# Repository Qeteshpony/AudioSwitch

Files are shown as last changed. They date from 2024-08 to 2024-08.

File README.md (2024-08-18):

# AudioSwitch



3D Render

[Hardware Documentation](https://qeteshpony.github.io/AudioSwitch)

Takes one 6.3mm stereo or two 6.3mm mono plugs on each in- and output

The signal goes from the input to one of the outputs, depending on the switch position

Always use the left channel connector for stereo plugs, leave the right channel open in that case

Dual mono and single stereo conections can be mixed

### Needed parts

The audio connectors are NEUTRIK NRJ6HF - I use the -AU version because I can, but the standard version should work just fine

The switch is a C&K PVA2EEH31.7NV2

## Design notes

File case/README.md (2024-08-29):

The case is designed in a way so both parts can be printed without any supports. I printed them with a 0.6mm nozzle with .25mm layer height and arachne enabled and they came out perfect. 

Use two self-tapping M3-Screws to close the case with the board sandwiched between the two parts. 

The included lbx file can be printed on a P-Touch printer with 12mm tape. After cutting of a few mm on the right it can be aligned with the connectors. I used clear tape with white ink to get a nice effect on a black case.

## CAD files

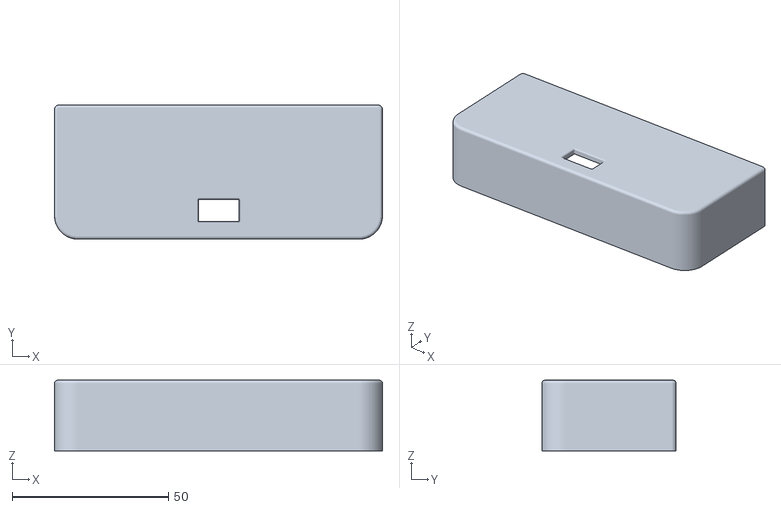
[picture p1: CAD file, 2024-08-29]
case/AudioSwitch Case Top.stl
105.0 x 43.0 x 22.6

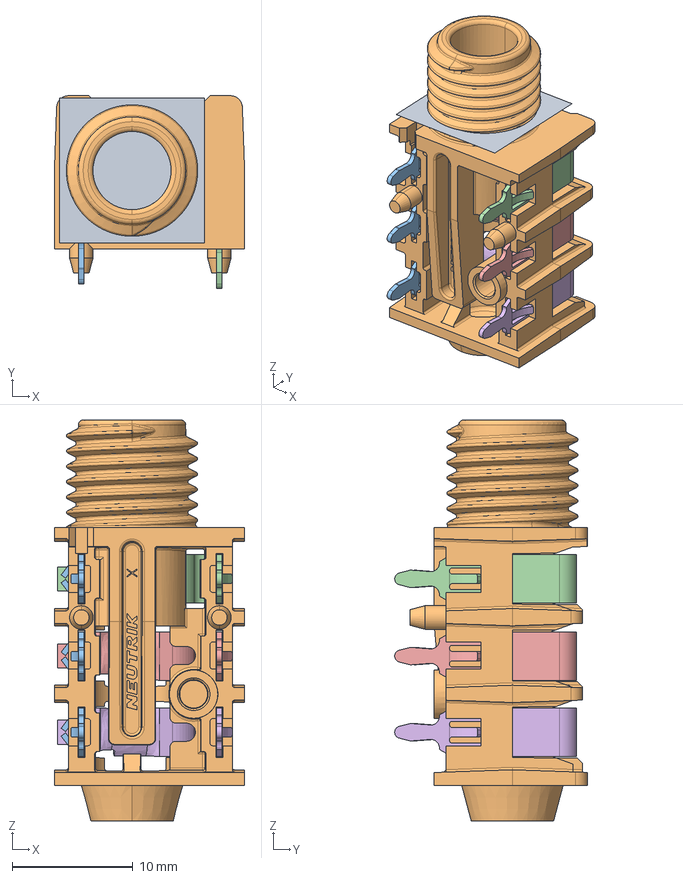
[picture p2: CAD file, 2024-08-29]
pcb/nrj6hf.stp
15.8 x 16.0 x 33.2 mm

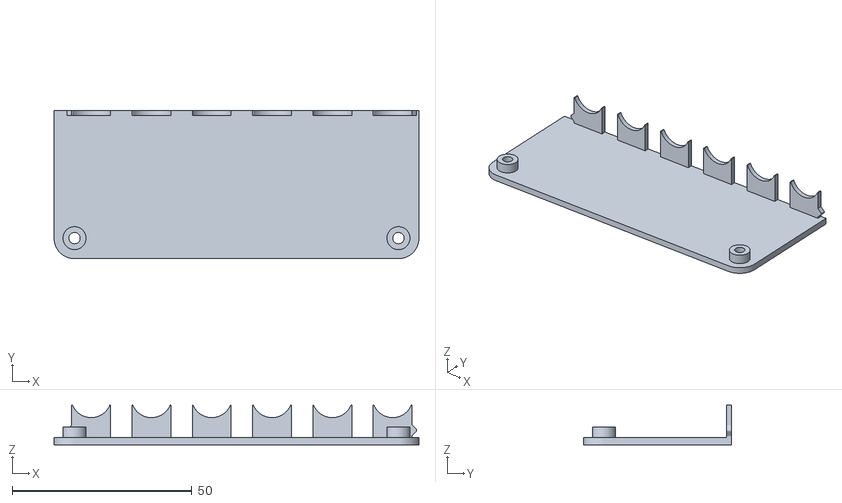
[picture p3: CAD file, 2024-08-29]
case/AudioSwitch Case Bottom.stl
101.4 x 41.2 x 11.0

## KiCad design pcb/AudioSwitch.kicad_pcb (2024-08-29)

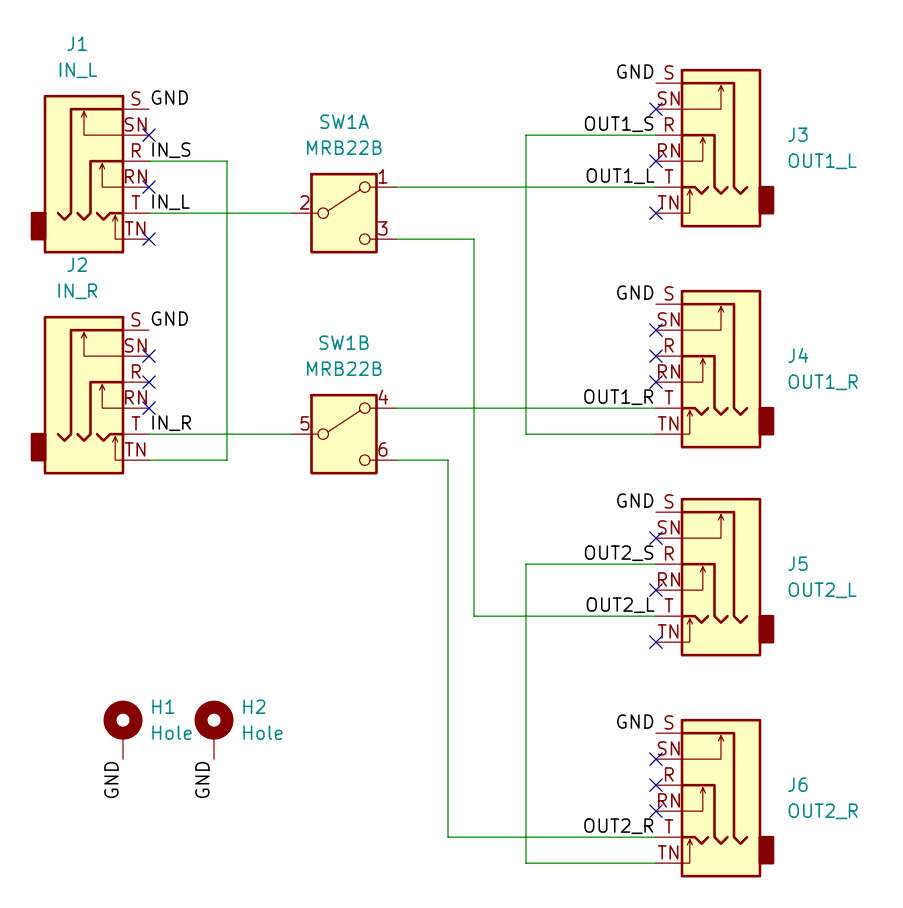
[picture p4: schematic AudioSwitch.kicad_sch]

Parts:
H1, H2: Hole; MountingHole_3.2mm_M3_Pad_Via
J1: IN_L; Jack_6.35mm_Neutrik_NRJ6HF-AU_Horizontal
J2: IN_R; Jack_6.35mm_Neutrik_NRJ6HF-AU_Horizontal
J3: OUT1_L; Jack_6.35mm_Neutrik_NRJ6HF-AU_Horizontal
J4: OUT1_R; Jack_6.35mm_Neutrik_NRJ6HF-AU_Horizontal
J5: OUT2_L; Jack_6.35mm_Neutrik_NRJ6HF-AU_Horizontal
J6: OUT2_R; Jack_6.35mm_Neutrik_NRJ6HF-AU_Horizontal
SW1: MRB22B; SW_Push_2P2T_Toggle_CK_PVA2xxH3xxxxxxV2

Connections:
/GND: H1.1, H2.1, J1.S, J2.S, J3.S, J4.S, J5.S, J6.S
/IN_L: J1.T, SW1.2 (B)
/IN_R: J2.T, SW1.5 (B)
/IN_S: J1.R, J2.TN
/OUT1_L: J3.T, SW1.1 (A)
/OUT1_R: J4.T, SW1.4 (A)
/OUT1_S: J3.R, J4.TN
/OUT2_L: J5.T, SW1.3 (C)
/OUT2_R: J6.T, SW1.6 (C)
/OUT2_S: J5.R, J6.TN

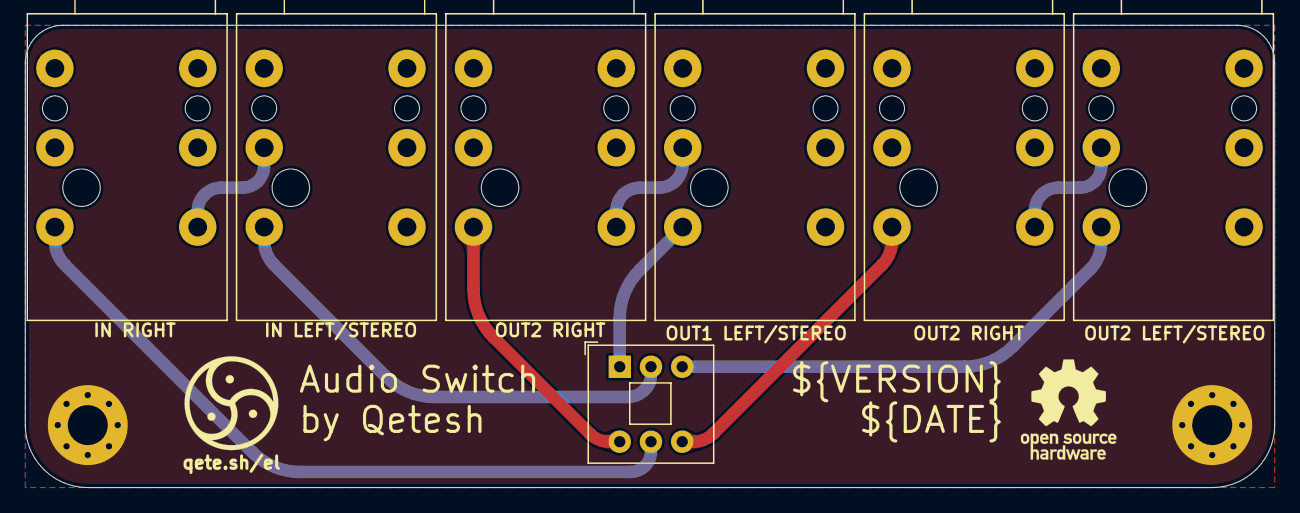
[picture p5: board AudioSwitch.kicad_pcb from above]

Board: 2 copper layers, 100.0 x 37.0 mm, 9 parts (0 on the bottom side), 10 nets.

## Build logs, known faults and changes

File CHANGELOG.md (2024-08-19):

# Changelog

## 1.0.0 (2024-08-19)

### Features

* initial commit ([d3c52cb](https://github.com/Qeteshpony/AudioSwitch/commit/d3c52cb936feac413439092e50b9f1e02347a7c6))

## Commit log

2024-08-18 feat: initial commit
    [AudioSwitch.kicad_pcb, AudioSwitch.kicad_sch]
2024-08-19 style: add tear drops and rounded tracks
    [AudioSwitch.kicad_pcb]
2024-08-19 docs: clean up schematics
    [AudioSwitch.kicad_sch]
2024-08-29 docs: add 3d model for connector
    [AudioSwitch.kicad_pcb, nrj6hf.stp]
2024-08-29 feat(case): add files for case
    [AudioSwitch Case Bottom.stl, AudioSwitch Case Top.stl]
2024-08-29 docs(case): add readme
